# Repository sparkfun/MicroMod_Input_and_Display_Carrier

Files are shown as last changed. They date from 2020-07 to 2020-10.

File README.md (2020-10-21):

# SparkFun MicroMod Input and Display Carrier Board
========================================

SparkFun MicroMod Input and Display Carrier Board

[*SparkFun MicroMod Input and Display Carrier Board (16985)*](https://www.sparkfun.com/products/16985)

The SparkFun MicroMod Input and Display Carrier Board is a great way to add data and input visibility to your MicroMod project. Want to create your own embedded game? How about displaying data that is remotely collected and transmitted by your SparkFun MicroMod Weather Carrier Board and its processor? This is a great option. 

This carrier board combines a 2.4" TFT display, 6 addressable LEDs, onboard voltage regulator, a 6 pin IO connector, and microSD slot with the M.2 pin connector slot so that it can be used with compatible processor boards in our MicroMod ecosystem. 

Repository Contents
-------------------
* **/Firmware** - Example code specific to the Input and Display Carrier Board.
* **/Hardware** - Eagle design files (.brd, .sch)
* **/Production** - Production panel files (.brd)

Documentation
--------------
* **[Hookup Guide](https://learn.sparkfun.com/tutorials/sparkfun-micromod-input-and-display-carrier-board-hookup-guide)** - Basic hookup guide for the SparkFun MicroMod Input and Display Carrier Board.
* **[SparkFun Graphical Datasheets](https://github.com/sparkfun/Graphical_Datasheets)** -Graphical Datasheets for various SparkFun products.
* **[SparkFun HyperDisplay](https://github.com/sparkfun/SparkFun_HyperDisplay/archive/master.zip)** - Base level HyperDisplay library.
* **[SparkFun HyperDisplay ILI9341 Arduino Library](https://github.com/sparkfun/HyperDisplay_ILI9341_ArduinoLibrary/archive/master.zip)** - Mid level HyperDisplay library.
* **[SparkFun_HyperDisplay 4DLCD-320240 Arduino Library](https://github.com/sparkfun/HyperDisplay_4DLCD-320240_ArduinoLibrary/archive/master.zip)** -  Top level HyperDisplay library for the SparkFun MicroMod Input and Display Carrier Board. This library contains the examples for using the Input and Display Carrier Board.
* **[SparkFun MicroMod Button Arduino Library](https://github.com/sparkfun/SparkFun_MicroMod_Button_Arduino_Library)** - Example library to allow the user to determine if buttons on the board are pressed.  
* **[Getting Started with MicroMod](https://learn.sparkfun.com/tutorials/getting-started-with-micromod)** - A tutorial to help you get started with the MicroMod Ecosystem. 
* **[Designing with MicroMod](https://learn.sparkfun.com/tutorials/designing-with-micromod)** - A tutorial to walk you through the specs of the MicroMod processor and carrier board as well as the basics of incorporating the MicroMod form factor into your own PCB designs.

License Information
-------------------

This product is _**open source**_! 

Please review the LICENSE.md file for license information. 

If you have any questions or concerns on licensing, please contact technical support on our [SparkFun forums](https://forum.sparkfun.com/viewforum.php?f=152).

Distributed as-is; no warranty is given.

- Your friends at SparkFun.

_<COLLABORATION CREDIT>_

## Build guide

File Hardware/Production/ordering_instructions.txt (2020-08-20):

panel size, 129x178mm
PCB thickness, 1.6mm
number of layers, 2
soldermask color, Red
silkscreen color, White
oz copper, 1oz
finish, HASL lead free
stencils, top+bottom
pcs per panel, 4
min trace width, 0.1778mm / 0.0070in
min drill size, 0.3810mm / 0.0150in

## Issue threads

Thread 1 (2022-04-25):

Debouncing logic can cause button release to be missed

cbiffle, 2022-04-25:
Because the debouncing logic delays _all_ pin change interrupts, and not further interrupts from the pin that is being debounced, pressing any two buttons and then releasing them at roughly the same time can cause one to stay "pressed," from the perspective of the pressed/clicked registers.

The problem is here: https://github.com/sparkfun/MicroMod_Input_and_Display_Carrier/blob/master/Firmware/Input_and_Display_Button_Master/interrupts.ino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

...where the ISR is simply aborted if the debounce timer hasn't elapsed yet.

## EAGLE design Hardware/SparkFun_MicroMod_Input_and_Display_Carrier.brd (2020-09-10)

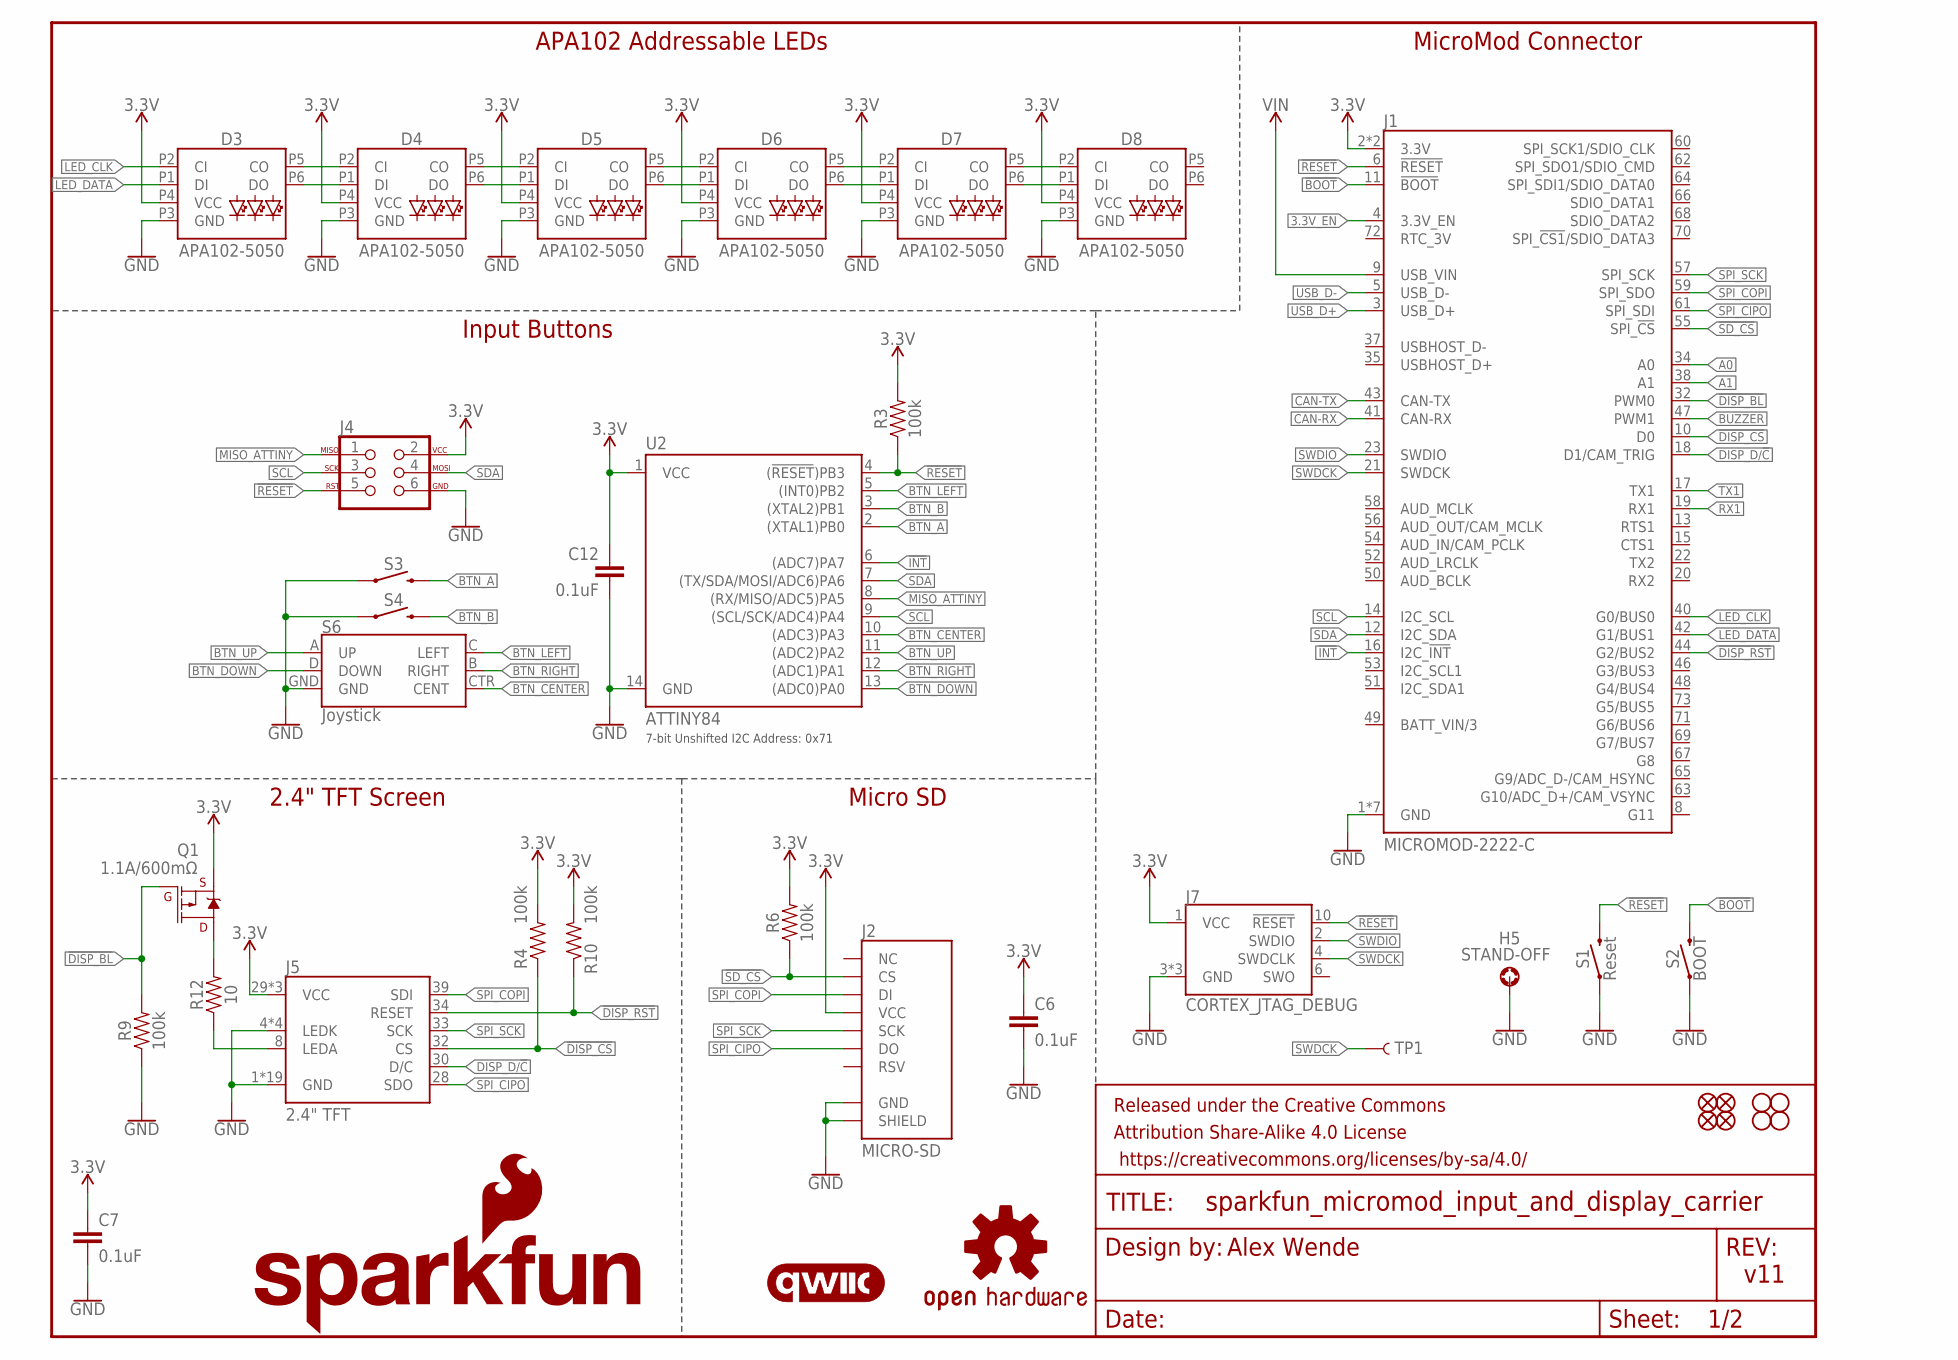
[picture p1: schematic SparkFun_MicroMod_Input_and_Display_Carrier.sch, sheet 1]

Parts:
C6, C7, C12: 0.1uF; 0603
D3, D4, D5, D6, D7, D8: APA102-5050
FD1, FD2, FD3, FD4: FIDUCIALUFIDUCIAL; FIDUCIAL-MICRO
FRAME1: FRAME-LETTER; CREATIVE_COMMONS
H1, H2, H3, H4: STAND-OFF
H5: STAND-OFF; STAND-OFF-REFLOW-M2.5
J1: MICROMOD-2222-C; M.2-CONNECTOR-E
J2: MICRO-SD; MICRO-SD-SOCKET
J4: AVR_SPI_PROG_3X2TESTPOINTS; 2X3_TEST_POINTS
J5: 2.4" TFT; FPC05040-17204
J7: CORTEX_JTAG_DEBUG; 2X5-PTH-1.27MM-NO_SILK
LOGO1: SFE_LOGO_NAME_FLAME.2_INCH; SFE_LOGO_NAME_FLAME_.2
LOGO2: QWIIC_LOGO_5MM; QWIIC_5MM
LOGO3: OSHW-LOGOS; OSHW-LOGO-S
Q1: 1.1A/600mΩ; SOT23-3
R3, R4, R6, R9, R10: 100k; 0603
R12: 10; 1206
S1: Reset; TACTILE_SWITCH_SMD_5.2MM
S2: BOOT; TACTILE_SWITCH_SMD_5.2MM
S3, S4: MOMENTARY-SWITCH-SPST-SMD-5.2MM-TALL; TACTILE_SWITCH_SMD_5.2MM
S6: Joystick; JOYSTICK_MINI
TP1: TEST-POINT3; PAD.03X.03
U2: ATTINY84; SO14

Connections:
3.3V: C6.1, C7.1, C12.1, D3.P4 (VCC), D4.P4 (VCC), D5.P4 (VCC), D6.P4 (VCC), D7.P4 (VCC), D8.P4 (VCC), J1.2 (3.3V), J1.74 (3.3V), J2.VCC, J4.2, J5.29 (VCC), J5.31 (VCC), J5.38 (VCC), J7.1 (VCC), Q1.2 (S), R3.2, R4.2, R6.2, R10.2, U2.1 (VCC); also elsewhere on the board
3.3V_EN: J1.4 (3.3V_EN); also elsewhere on the board
!BOOT: J1.11 (!BOOT!), S2.3 (2), S2.4 (2)
!DISP_BL: J1.32 (PWM0), Q1.1 (G), R9.2
!DISP_CS: J1.10 (D0), J5.32 (CS), R4.1
!DISP_RST: J1.44 (G2/BUS2), J5.34 (RESET), R10.1
!INT: J1.16 (I2C_!INT!), U2.6 ((ADC7)PA7)
!RESET: J1.6 (!RESET!), J4.5, J7.10 (!RESET), R3.1, S1.3 (2), S1.4 (2), U2.4 ((!RESET!)PB3)
!SD_CS: J1.55 (SPI_!CS!), J2.CS, R6.1
A0: J1.34 (A0); also elsewhere on the board
A1: J1.38 (A1); also elsewhere on the board
BTN_A: S3.3 (2), U2.2 ((XTAL1)PB0)
BTN_B: S4.3 (2), U2.3 ((XTAL2)PB1)
BTN_CENTER: S6.CTR (CENT), U2.10 ((ADC3)PA3)
BTN_DOWN: S6.D (DOWN), U2.13 ((ADC0)PA0)
BTN_LEFT: S6.C (LEFT), U2.5 ((INT0)PB2)
BTN_RIGHT: S6.B (RIGHT), U2.12 ((ADC1)PA1)
BTN_UP: S6.A (UP), U2.11 ((ADC2)PA2)
BUZZER: J1.47 (PWM1); also elsewhere on the board
CAN-RX: J1.41 (CAN-RX); also elsewhere on the board
CAN-TX: J1.43 (CAN-TX); also elsewhere on the board
DISP_D/!C: J1.18 (D1/CAM_TRIG), J5.30 (D/C)
GND: C6.2, C7.2, C12.2, D3.P3 (GND), D4.P3 (GND), D5.P3 (GND), D6.P3 (GND), D7.P3 (GND), D8.P3 (GND), H5.1, J1.1 (GND), J1.7 (GND), J1.33 (GND), J1.36 (GND), J1.39 (GND), J1.45 (GND), J1.75 (GND), J2.CD1 (SHIELD), J2.GND, J4.6, J5.1 (GND), J5.4 (LEDK), J5.5 (LEDK), J5.6 (LEDK), J5.7 (LEDK), J5.11 (GND), J5.12 (GND), J5.13 (GND), J5.14 (GND), J5.15 (GND), J5.16 (GND), J5.17 (GND), J5.18 (GND), J5.19 (GND), J5.20 (GND), J5.21 (GND), J5.22 (GND), J5.23 (GND), J5.24 (GND), J5.25 (GND), J5.26 (GND), J5.27 (GND), J5.40 (GND), J7.3 (GND), J7.5 (GND), J7.9 (GND), R9.1, S1.1, S1.2 (1), S2.1, S2.2 (1), S3.1, S4.1, S6.GND, U2.14 (GND); also elsewhere on the board
LED_CLK: D3.P2 (CI), J1.40 (G0/BUS0)
LED_DATA: D3.P1 (DI), J1.42 (G1/BUS1)
MISO_ATTINY: J4.1, U2.8 ((RX/MISO/ADC5)PA5)
unnamed: J5.8 (LEDA), R12.1
unnamed: Q1.3 (D), R12.2
unnamed: D3.P5 (CO), D4.P2 (CI)
unnamed: D3.P6 (DO), D4.P1 (DI)
unnamed: D4.P5 (CO), D5.P2 (CI)
unnamed: D4.P6 (DO), D5.P1 (DI)
unnamed: D5.P5 (CO), D6.P2 (CI)
unnamed: D5.P6 (DO), D6.P1 (DI)
unnamed: D6.P5 (CO), D7.P2 (CI)
unnamed: D6.P6 (DO), D7.P1 (DI)
unnamed: D7.P5 (CO), D8.P2 (CI)
unnamed: D7.P6 (DO), D8.P1 (DI)
RX1: J1.19 (RX1); also elsewhere on the board
SCL: J1.14 (I2C_SCL), J4.3, U2.9 ((SCL/SCK/ADC4)PA4); also elsewhere on the board
SDA: J1.12 (I2C_SDA), J4.4, U2.7 ((TX/SDA/MOSI/ADC6)PA6); also elsewhere on the board
SPI_CIPO: J1.61 (SPI_SDI), J2.DO, J5.28 (SDO)
SPI_COPI: J1.59 (SPI_SDO), J2.DI, J5.39 (SDI)
SPI_SCK: J1.57 (SPI_SCK), J2.SCLK (SCK), J5.33 (SCK)
SWDCK: J1.21 (SWDCK), J7.4 (SWDCLK), TP1.P$1
SWDIO: J1.23 (SWDIO), J7.2 (SWDIO)
TX1: J1.17 (TX1); also elsewhere on the board
USB_D+: J1.3 (USB_D+); also elsewhere on the board
USB_D-: J1.5 (USB_D-); also elsewhere on the board
VIN: J1.9 (USB_VIN); also elsewhere on the board

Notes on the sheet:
7-bit Unshifted I2C Address: 0x71
Alex Wende
v11
Micro SD
2.4" TFT Screen
Input Buttons
APA102 Addressable LEDs
MicroMod Connector

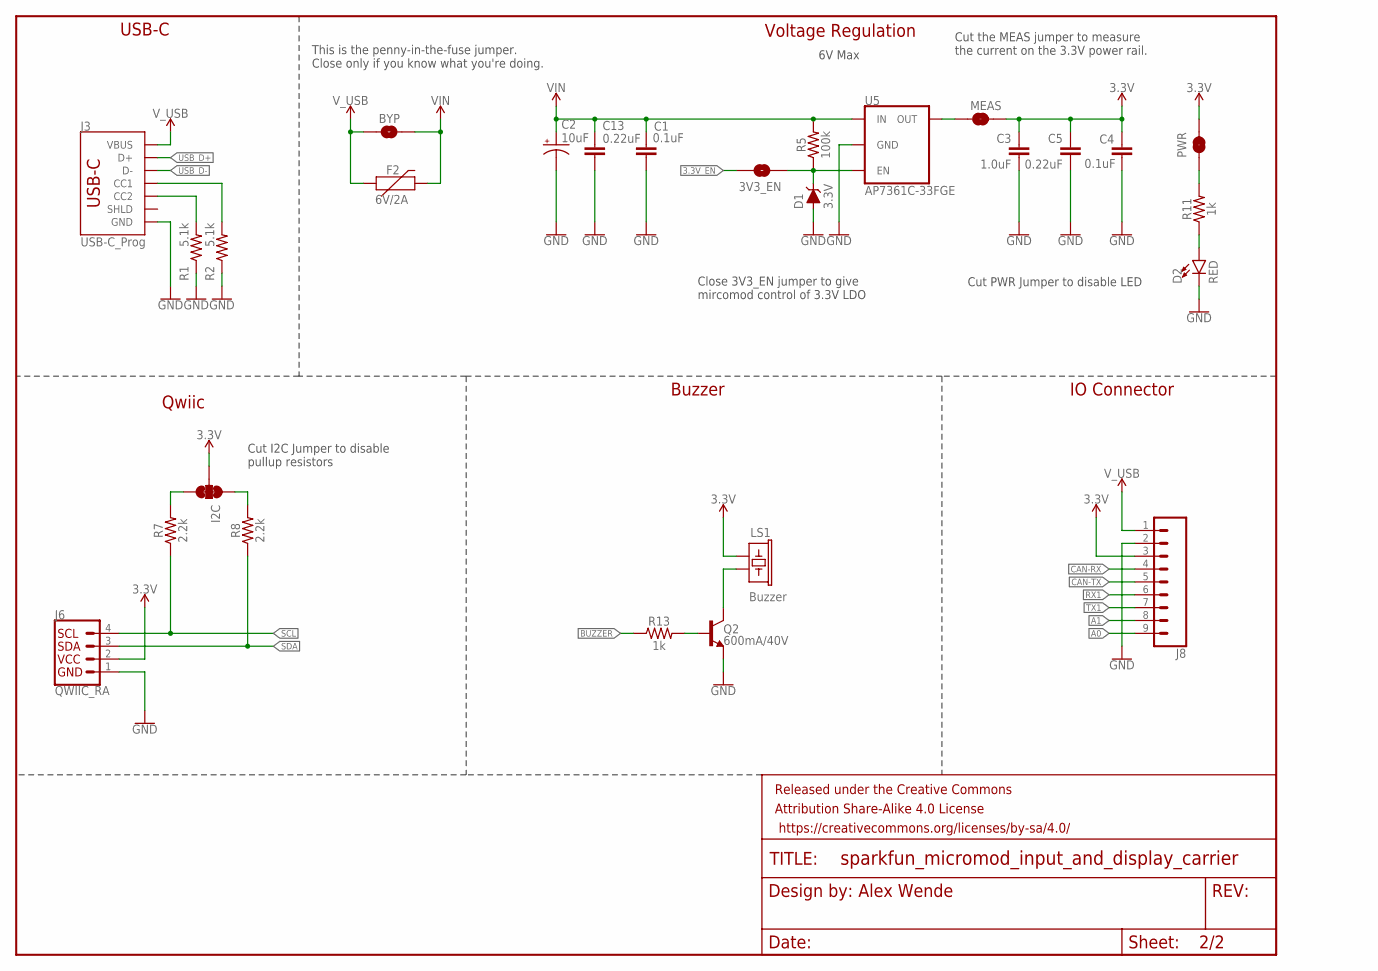
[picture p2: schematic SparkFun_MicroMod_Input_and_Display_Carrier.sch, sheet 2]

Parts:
3V3_EN: JUMPER-SMT_2_NO_SILK; SMT-JUMPER_2_NO_SILK
BYP: JUMPER-SMT_2_NO_SILK; SMT-JUMPER_2_NO_SILK
C1, C4: 0.1uF; 0603
C2: 10uF; EIA3216
C3: 1.0uF; 0603
C5, C13: 0.22uF; 0603
D1: 3.3V; SOD-323
D2: RED; LED-0603
F2: 6V/2A; 1210
FRAME2: FRAME-LETTERNO_PACKAGE; DUMMY
I2C: JUMPER-SMT_3_2-NC_TRACE_SILK; SMT-JUMPER_3_2-NC_TRACE_SILK
J3: USB-C_Prog; USB-C-16P-2LAYER-PADS
J6: QWIIC_RA; JST04_1MM_RA
J8: CONN_09NO_SILK; 1X09_NO_SILK
LS1: Buzzer; BUZZER-CCV
MEAS: JUMPER-COMBO_2_NC_TRACE; COMBO-JUMPER_2_NC_TRACE
PWR: JUMPER-SMT_2_NC_TRACE_SILK; SMT-JUMPER_2_NC_TRACE_SILK
Q2: 600mA/40V; SOT23-3
R1, R2: 5.1k; 0603
R5: 100k; 0603
R7, R8: 2.2k; 0603
R11, R13: 1k; 0603
U5: AP7361C-33FGE; UDFN-8

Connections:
3.3V: C3.1, C4.1, C5.1, I2C.2, J6.2, J8.3, LS1.+ (1), MEAS.2, MEAS.4 (2), PWR.2; also elsewhere on the board
3.3V_EN: 3V3_EN.1; also elsewhere on the board
A0: J8.9; also elsewhere on the board
A1: J8.8; also elsewhere on the board
BUZZER: R13.1; also elsewhere on the board
CAN-RX: J8.4; also elsewhere on the board
CAN-TX: J8.5; also elsewhere on the board
ENABLE: 3V3_EN.2, D1.C, R5.1, U5.5 (EN)
GND: C1.2, C2.-, C3.2, C4.2, C5.2, C13.2, D1.A, D2.C, J3.GND, J3.GND2 (GND), J6.1, J8.2, Q2.2 (E), R1.1, R2.1, U5.4 (GND), U5.EP (GND); also elsewhere on the board
unnamed: I2C.3, R7.2
unnamed: I2C.1, R8.2
unnamed: LS1.- (2), Q2.3 (C)
unnamed: Q2.1 (B), R13.2
unnamed: J3.A5 (CC1), R2.2
unnamed: J3.B5 (CC2), R1.2
unnamed: PWR.1, R11.2
unnamed: D2.A, R11.1
unnamed: MEAS.1, MEAS.3 (1), U5.1 (OUT)
RX1: J8.6; also elsewhere on the board
SCL: J6.4, R7.1; also elsewhere on the board
SDA: J6.3, R8.1; also elsewhere on the board
TX1: J8.7; also elsewhere on the board
USB_D+: J3.A6 (D+), J3.B6 (D+); also elsewhere on the board
USB_D-: J3.A7 (D-), J3.B7 (D-); also elsewhere on the board
VIN: BYP.2, C1.1, C2.+, C13.1, F2.2, R5.2, U5.8 (IN); also elsewhere on the board
V_USB: BYP.1, F2.1, J3.VBUS1 (VBUS), J3.VBUS2 (VBUS), J8.1

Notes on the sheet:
This is the penny-in-the-fuse jumper. Close only if you know what you're doing.
Voltage Regulation
USB-C
Alex Wende
Qwiic
Cut PWR Jumper to disable LED
Cut I2C Jumper to disable pullup resistors
Close 3V3_EN jumper to give mircomod control of 3.3V LDO
Buzzer
IO Connector
6V Max
Cut the MEAS jumper to measure the current on the 3.3V power rail.

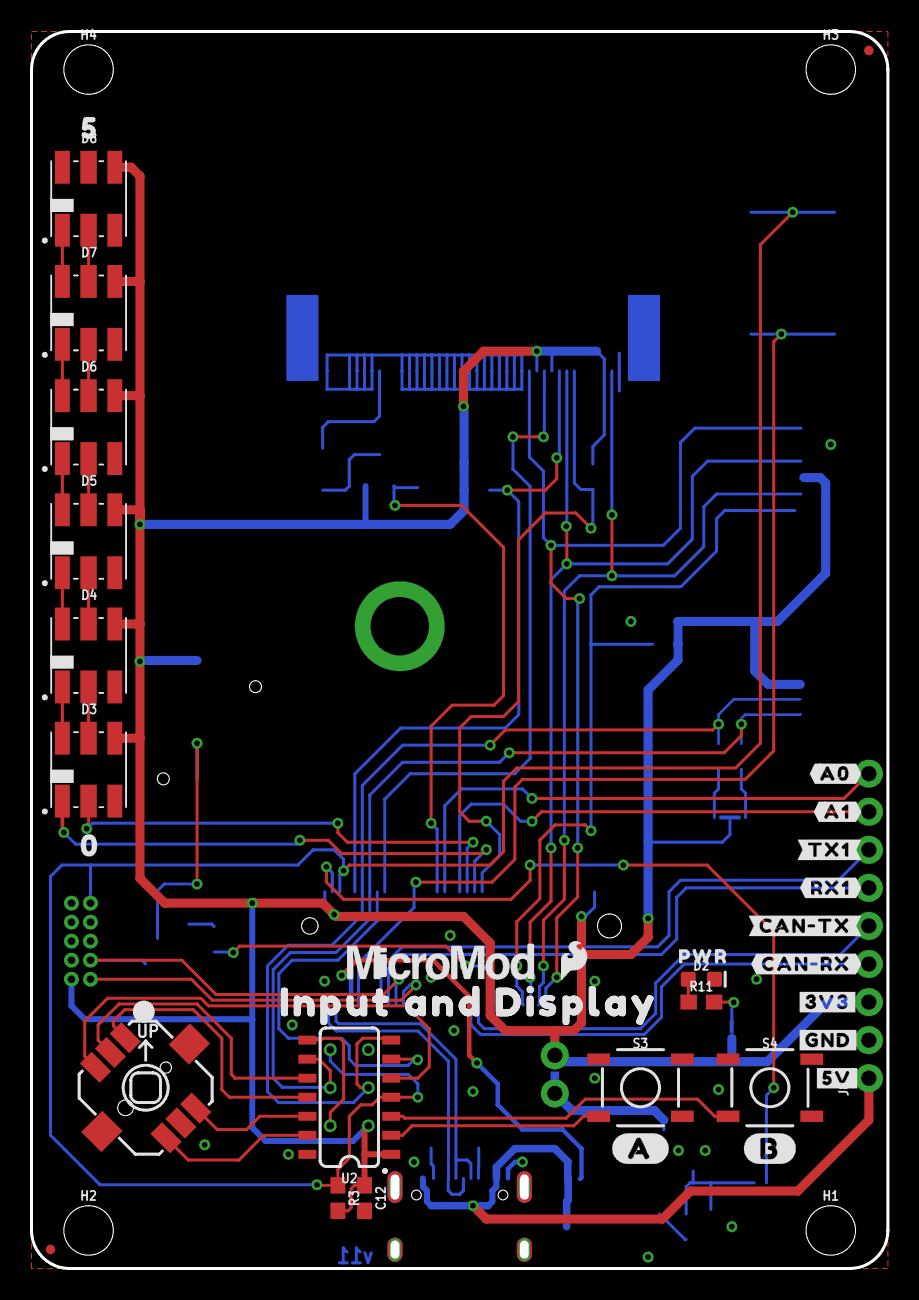
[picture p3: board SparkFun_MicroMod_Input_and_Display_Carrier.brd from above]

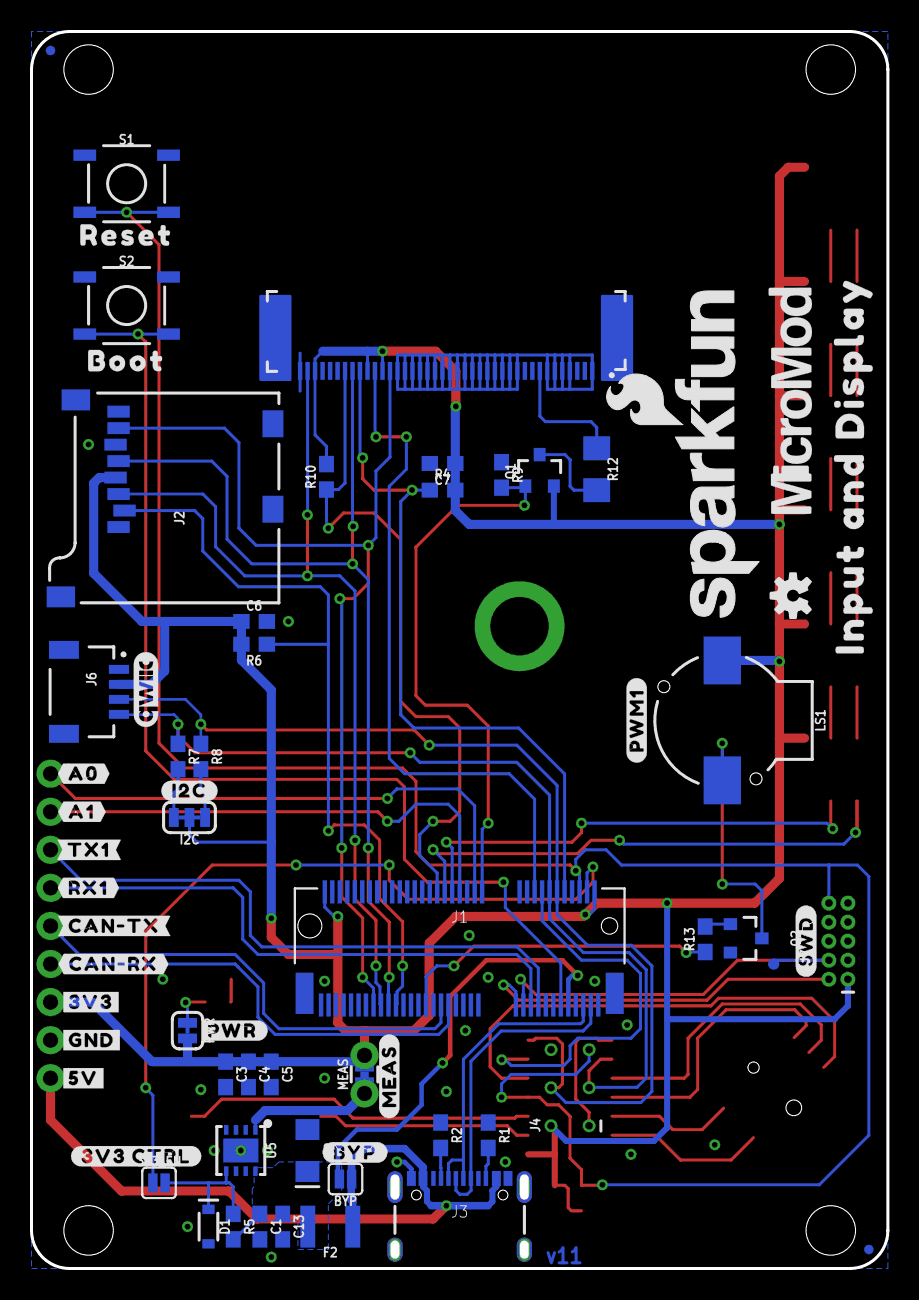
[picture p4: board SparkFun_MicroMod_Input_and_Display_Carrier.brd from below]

Board: 2 copper layers, 57.1 x 82.5 mm, 107 parts (66 on the bottom side), 61 nets.

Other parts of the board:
U$1: MICROMOD_LOGO_.5
U$2, U$16, U$17: INPUT_AND_DISPLAY0
U$3: SFE_LOGO_FLAME_.1
U$4: BOOT0
U$5: #A#0
U$6: #B#0
U$7: 00
U$8: 50
U$9: RESET0
U$10: MICROMOD_LOGO_.6
U$11: #MEAS#0
U$12: #I2C#0
U$13: PWR0
U$14: #BYP#0
U$15: #SWD#0
U$18, U$38: #5V#0
U$19: #PWR#0
U$20: #3V3_CTRL#0
U$21: #PWM1#0
U$22, U$23: #A0#0
U$24, U$25: #A1#0
U$26, U$27: #TX1#0
U$28, U$31: #3V3#0
U$29, U$30: #GND#0
U$32, U$33: #RX1#0
U$34, U$35: #CAN#RX#0
U$36, U$37: #CAN#TX#0

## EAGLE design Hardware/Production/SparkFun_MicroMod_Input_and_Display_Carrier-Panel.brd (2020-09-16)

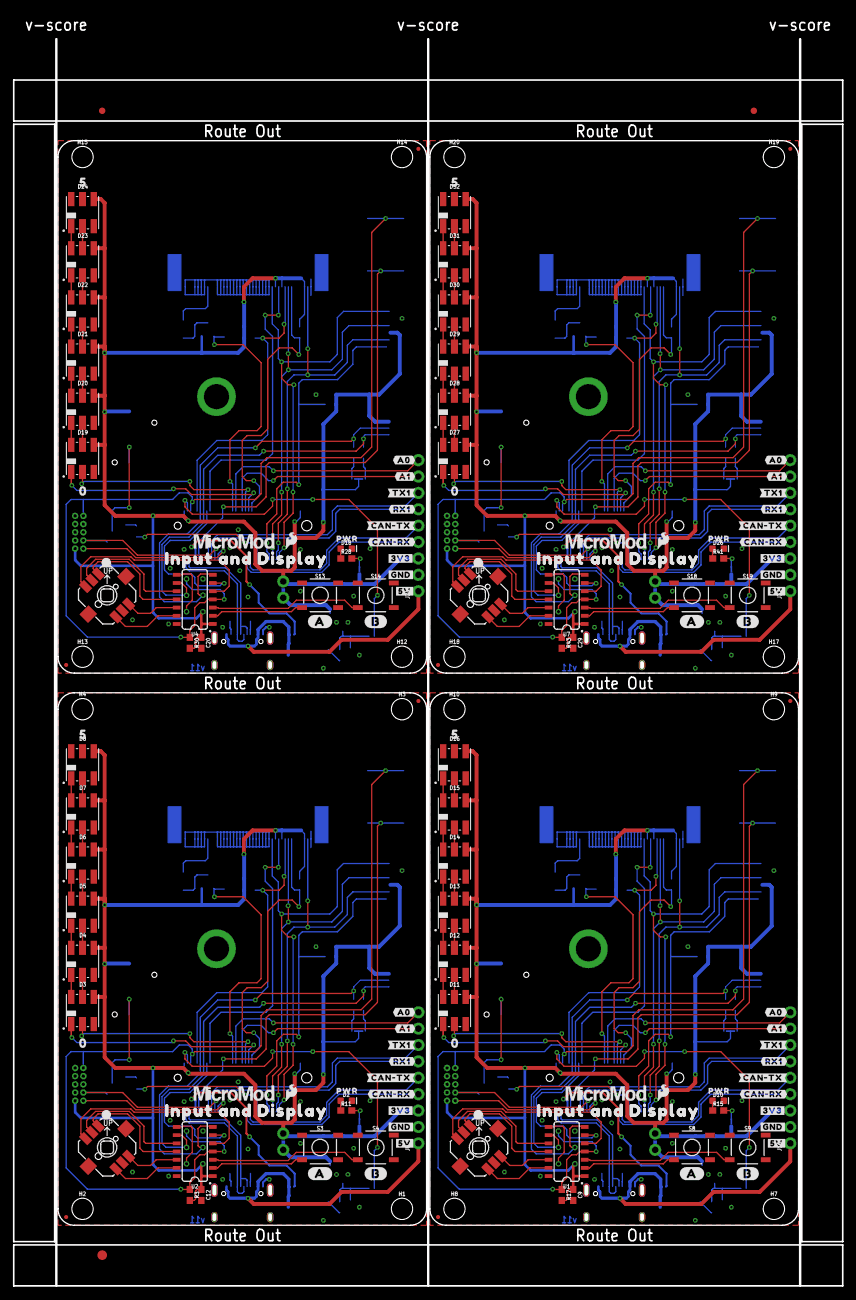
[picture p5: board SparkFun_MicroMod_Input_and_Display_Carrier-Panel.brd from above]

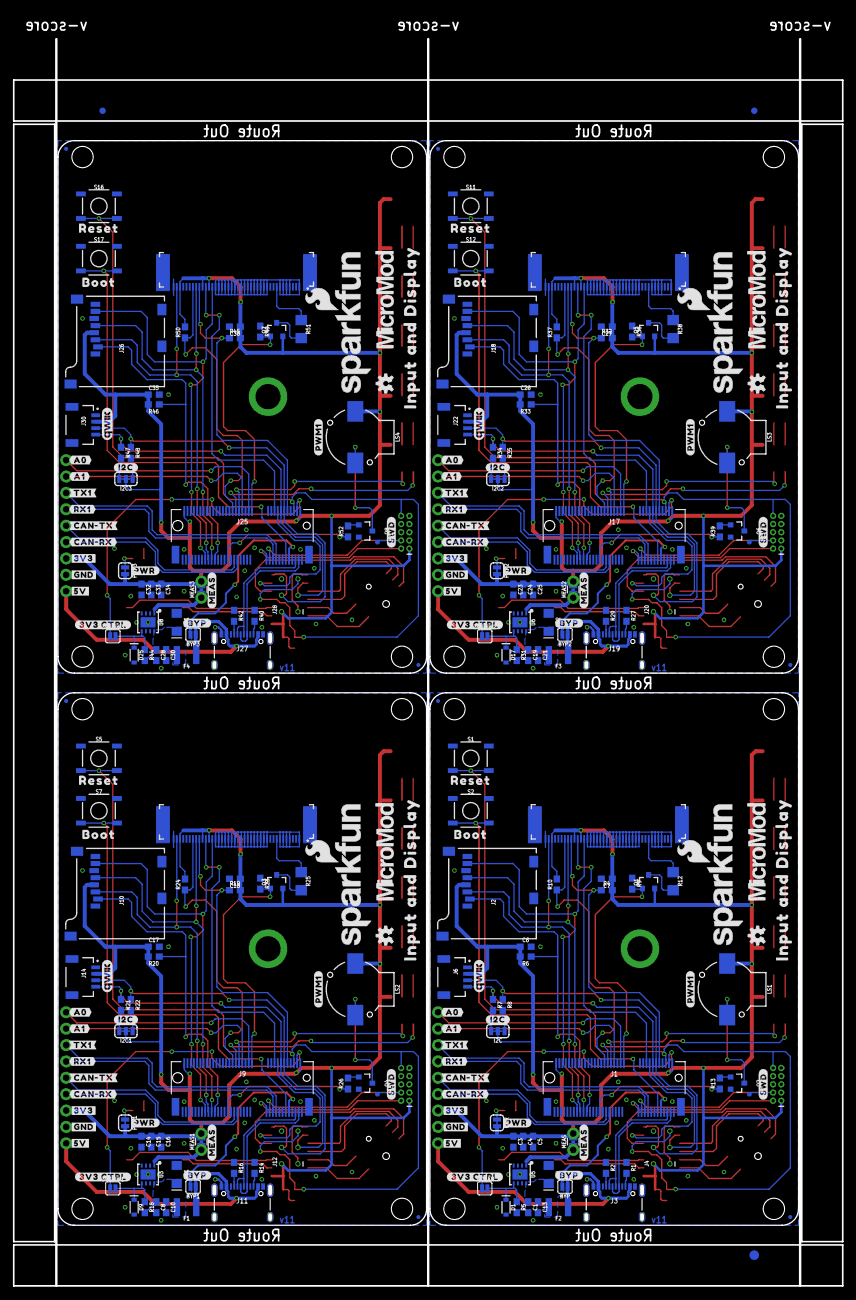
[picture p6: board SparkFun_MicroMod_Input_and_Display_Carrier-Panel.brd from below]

Board: 2 copper layers, 128.5 x 193.3 mm, 434 parts (267 on the bottom side), 244 nets.

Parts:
3V3_EN, 3V3_EN1, 3V3_EN2, 3V3_EN3: SMT-JUMPER_2_NO_SILK
BYP, BYP1, BYP2, BYP3: JUMPER-SMT_2_NO_SILK; SMT-JUMPER_2_NO_SILK
C1, C4, C6, C7, C8, C9, C12, C15, C17, C18, C19, C20, C24, C26, C27, C28, C29, C33, C35, C36: 0.1uF; 0603
C2, C11, C22, C31: 10uF; EIA3216
C3, C14, C23, C32: 1.0uF; 0603
C5, C10, C13, C16, C21, C25, C30, C34: 0.22uF; 0603
D1, D9, D17, D25: 3.3V; SOD-323
D2, D10, D18, D26: RED; LED-0603
D3, D4, D5, D6, D7, D8, D11, D12, D13, D14, D15, D16, D19, D20, D21, D22, D23, D24, D27, D28, D29, D30, D31, D32: APA102-5050
E$1, E$2, E$3, E$4: FIDUCIAL-1X2
E$5, E$6: FIDUCIAL-1.5X3
F1, F2, F3, F4: 6V/2A; 1210
FD1, FD2, FD3, FD4, FD5, FD6, FD7, FD8, FD9, FD10, FD11, FD12, FD13, FD14, FD15, FD16: FIDUCIALUFIDUCIAL; FIDUCIAL-MICRO
FRAME1, FRAME3, FRAME5, FRAME7: FRAME-LETTER; CREATIVE_COMMONS
FRAME2, FRAME4, FRAME6, FRAME8: FRAME-LETTERNO_PACKAGE; DUMMY
H1, H2, H3, H4, H7, H8, H9, H10, H12, H13, H14, H15, H17, H18, H19, H20: STAND-OFF
H5, H6, H11, H16: STAND-OFF; STAND-OFF-REFLOW-M2.5
I2C, I2C1, I2C2, I2C3: SMT-JUMPER_3_2-NC_TRACE_SILK
J1, J9, J17, J25: MICROMOD-2222-C; M.2-CONNECTOR-E
J2, J10, J18, J26: MICRO-SD; MICRO-SD-SOCKET
J3, J11, J19, J27: USB-C_Prog; USB-C-16P-2LAYER-PADS
J4, J12, J20, J28: AVR_SPI_PROG_3X2TESTPOINTS; 2X3_TEST_POINTS
J5, J13, J21, J29: 2.4" TFT; FPC05040-17204
J6, J14, J22, J30: QWIIC_RA; JST04_1MM_RA
J7, J15, J23, J31: CORTEX_JTAG_DEBUG; 2X5-PTH-1.27MM-NO_SILK
J8, J16, J24, J32: 1X09_NO_SILK
LOGO1, LOGO4, LOGO7, LOGO10: SFE_LOGO_NAME_FLAME.2_INCH; SFE_LOGO_NAME_FLAME_.2
LOGO2, LOGO5, LOGO8, LOGO11: QWIIC_LOGO_5MM; QWIIC_5MM
LOGO3, LOGO6, LOGO9, LOGO12: OSHW-LOGOS; OSHW-LOGO-S
LS1, LS2, LS3, LS4: Buzzer; BUZZER-CCV
MEAS, MEAS1, MEAS2, MEAS3: COMBO-JUMPER_2_NC_TRACE
PWR, PWR1, PWR2, PWR3: SMT-JUMPER_2_NC_TRACE_SILK
Q1, Q3, Q5, Q7: 1.1A/600mΩ; SOT23-3
Q2, Q4, Q6, Q8: 600mA/40V; SOT23-3
R1, R2, R14, R16, R27, R29, R40, R42: 5.1k; 0603
R3, R4, R5, R6, R9, R10, R17, R18, R19, R20, R23, R24, R30, R31, R32, R33, R36, R37, R43, R44, R45, R46, R49, R50: 100k; 0603
R7, R8, R21, R22, R34, R35, R47, R48: 2.2k; 0603
R11, R13, R15, R26, R28, R39, R41, R52: 1k; 0603
R12, R25, R38, R51: 10; 1206
S1, S5, S11, S16: Reset; TACTILE_SWITCH_SMD_5.2MM
S2, S7, S12, S17: BOOT; TACTILE_SWITCH_SMD_5.2MM
S3, S4, S8, S9, S13, S14, S18, S19: MOMENTARY-SWITCH-SPST-SMD-5.2MM-TALL; TACTILE_SWITCH_SMD_5.2MM
S6, S10, S15, S20: Joystick; JOYSTICK_MINI
TP1, TP2, TP3, TP4: PAD.03X.03
U1, U2, U4, U7: ATTINY84; SO14
U3, U5, U6, U8: AP7361C-33FGE; UDFN-8
U$1, U$39, U$77, U$115: MICROMOD_LOGO_.5
U$2, U$16, U$17, U$40, U$54, U$55, U$78, U$92, U$93, U$116, U$130, U$131: INPUT_AND_DISPLAY0
U$3, U$45, U$83, U$121: SFE_LOGO_FLAME_.1
U$4, U$46, U$84, U$122: BOOT0
U$5, U$41, U$79, U$117: #A#0
U$6, U$42, U$80, U$118: #B#0
U$7, U$43, U$81, U$119: 00
U$8, U$44, U$82, U$120: 50
U$9, U$47, U$85, U$123: RESET0
U$10, U$51, U$89, U$127: MICROMOD_LOGO_.6
U$11, U$48, U$86, U$124: #MEAS#0
U$12, U$49, U$87, U$125: #I2C#0
U$13, U$50, U$88, U$126: PWR0
U$14, U$52, U$90, U$128: #BYP#0
U$15, U$53, U$91, U$129: #SWD#0
U$18, U$38, U$75, U$76, U$113, U$114, U$151, U$152: #5V#0
U$19, U$56, U$94, U$132: #PWR#0
U$20, U$57, U$95, U$133: #3V3_CTRL#0
U$21, U$58, U$96, U$134: #PWM1#0
U$22, U$23, U$63, U$64, U$101, U$102, U$139, U$140: #A0#0
U$24, U$25, U$65, U$66, U$103, U$104, U$141, U$142: #A1#0
U$26, U$27, U$67, U$68, U$105, U$106, U$143, U$144: #TX1#0
U$28, U$31, U$59, U$62, U$97, U$100, U$135, U$138: #3V3#0
U$29, U$30, U$60, U$61, U$98, U$99, U$136, U$137: #GND#0
U$32, U$33, U$69, U$70, U$107, U$108, U$145, U$146: #RX1#0
U$34, U$35, U$71, U$72, U$109, U$110, U$147, U$148: #CAN#RX#0
U$36, U$37, U$73, U$74, U$111, U$112, U$149, U$150: #CAN#TX#0

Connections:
3.3V: C3.1, C4.1, C5.1, C6.1, C7.1, C12.1, D3.P4, D4.P4, D5.P4, D6.P4, D7.P4, D8.P4, I2C.2, J1.2, J1.74, J2.VCC, J4.2, J5.29, J5.31, J5.38, J6.2, J7.1, J8.3, LS1.+, MEAS.2, MEAS.4, PWR.2, Q1.2, R3.2, R4.2, R6.2, R10.2, U2.1
3.3V1: C9.1, C14.1, C15.1, C16.1, C17.1, C18.1, D11.P4, D12.P4, D13.P4, D14.P4, D15.P4, D16.P4, I2C1.2, J9.2, J9.74, J10.VCC, J12.2, J13.29, J13.31, J13.38, J14.2, J15.1, J16.3, LS2.+, MEAS1.2, MEAS1.4, PWR1.2, Q3.2, R17.2, R19.2, R20.2, R24.2, U1.1
3.3V2: C20.1, C23.1, C24.1, C25.1, C26.1, C27.1, D19.P4, D20.P4, D21.P4, D22.P4, D23.P4, D24.P4, I2C2.2, J17.2, J17.74, J18.VCC, J20.2, J21.29, J21.31, J21.38, J22.2, J23.1, J24.3, LS3.+, MEAS2.2, MEAS2.4, PWR2.2, Q5.2, R30.2, R32.2, R33.2, R37.2, U4.1
3.3V3: C29.1, C32.1, C33.1, C34.1, C35.1, C36.1, D27.P4, D28.P4, D29.P4, D30.P4, D31.P4, D32.P4, I2C3.2, J25.2, J25.74, J26.VCC, J28.2, J29.29, J29.31, J29.38, J30.2, J31.1, J32.3, LS4.+, MEAS3.2, MEAS3.4, PWR3.2, Q7.2, R43.2, R45.2, R46.2, R50.2, U7.1
3.3V_EN: 3V3_EN.1, J1.4
3.3V_EN1: 3V3_EN1.1, J9.4
3.3V_EN2: 3V3_EN2.1, J17.4
3.3V_EN3: 3V3_EN3.1, J25.4
!BOOT: J1.11, S2.3, S2.4
!BOOT1: J9.11, S7.3, S7.4
!BOOT2: J17.11, S12.3, S12.4
!BOOT3: J25.11, S17.3, S17.4
!DISP_BL: J1.32, Q1.1, R9.2
!DISP_BL1: J9.32, Q3.1, R23.2
!DISP_BL2: J17.32, Q5.1, R36.2
!DISP_BL3: J25.32, Q7.1, R49.2
!DISP_CS: J1.10, J5.32, R4.1
!DISP_CS1: J9.10, J13.32, R19.1
!DISP_CS2: J17.10, J21.32, R32.1
!DISP_CS3: J25.10, J29.32, R45.1
!DISP_RST: J1.44, J5.34, R10.1
!DISP_RST1: J9.44, J13.34, R24.1
!DISP_RST2: J17.44, J21.34, R37.1
!DISP_RST3: J25.44, J29.34, R50.1
!INT: J1.16, U2.6
!INT1: J9.16, U1.6
!INT2: J17.16, U4.6
!INT3: J25.16, U7.6
!RESET: J1.6, J4.5, J7.10, R3.1, S1.3, S1.4, U2.4
!RESET1: J9.6, J12.5, J15.10, R17.1, S5.3, S5.4, U1.4
!RESET2: J17.6, J20.5, J23.10, R30.1, S11.3, S11.4, U4.4
!RESET3: J25.6, J28.5, J31.10, R43.1, S16.3, S16.4, U7.4
!SD_CS: J1.55, J2.CS, R6.1
!SD_CS1: J9.55, J10.CS, R20.1
!SD_CS2: J17.55, J18.CS, R33.1
!SD_CS3: J25.55, J26.CS, R46.1
A0: J1.34, J8.9
A1: J1.38, J8.8
A2: J9.34, J16.9
A3: J9.38, J16.8
A4: J17.34, J24.9
A5: J17.38, J24.8
A6: J25.34, J32.9
A7: J25.38, J32.8
BTN_A: S3.3, U2.2
BTN_A1: S8.3, U1.2
BTN_A2: S13.3, U4.2
BTN_A3: S18.3, U7.2
BTN_B: S4.3, U2.3
BTN_B1: S9.3, U1.3
BTN_B2: S14.3, U4.3
BTN_B3: S19.3, U7.3
BTN_CENTER: S6.CTR, U2.10
BTN_CENTER1: S10.CTR, U1.10
BTN_CENTER2: S15.CTR, U4.10
BTN_CENTER3: S20.CTR, U7.10
BTN_DOWN: S6.D, U2.13
BTN_DOWN1: S10.D, U1.13
BTN_DOWN2: S15.D, U4.13
BTN_DOWN3: S20.D, U7.13
BTN_LEFT: S6.C, U2.5
BTN_LEFT1: S10.C, U1.5
BTN_LEFT2: S15.C, U4.5
BTN_LEFT3: S20.C, U7.5
BTN_RIGHT: S6.B, U2.12
BTN_RIGHT1: S10.B, U1.12
BTN_RIGHT2: S15.B, U4.12
BTN_RIGHT3: S20.B, U7.12
BTN_UP: S6.A, U2.11
BTN_UP1: S10.A, U1.11
BTN_UP2: S15.A, U4.11
BTN_UP3: S20.A, U7.11
BUZZER: J1.47, R13.1
BUZZER1: J9.47, R26.1
BUZZER2: J17.47, R39.1
BUZZER3: J25.47, R52.1
CAN-RX: J1.41, J8.4
CAN-RX1: J9.41, J16.4
CAN-RX2: J17.41, J24.4
CAN-RX3: J25.41, J32.4
CAN-TX: J1.43, J8.5
CAN-TX1: J9.43, J16.5
CAN-TX2: J17.43, J24.5
CAN-TX3: J25.43, J32.5
DISP_D/!C: J1.18, J5.30
DISP_D/!C1: J9.18, J13.30
DISP_D/!C2: J17.18, J21.30
DISP_D/!C3: J25.18, J29.30
ENABLE: 3V3_EN.2, D1.C, R5.1, U5.5
ENABLE1: 3V3_EN1.2, D9.C, R18.1, U3.5
ENABLE2: 3V3_EN2.2, D17.C, R31.1, U6.5
ENABLE3: 3V3_EN3.2, D25.C, R44.1, U8.5
GND: C1.2, C2.-, C3.2, C4.2, C5.2, C6.2, C7.2, C12.2, C13.2, D1.A, D2.C, D3.P3, D4.P3, D5.P3, D6.P3, D7.P3, D8.P3, H5.1, J1.1, J1.7, J1.33, J1.36, J1.39, J1.45, J1.75, J2.CD1, J2.GND, J3.GND, J3.GND2, J4.6, J5.1, J5.4, J5.5, J5.6, J5.7, J5.11, J5.12, J5.13, J5.14, J5.15, J5.16, J5.17, J5.18, J5.19, J5.20, J5.21, J5.22, J5.23, J5.24, J5.25, J5.26, J5.27, J5.40, J6.1, J7.3, J7.5, J7.9, J8.2, Q2.2, R1.1, R2.1, R9.1, S1.1, S1.2, S2.1, S2.2, S3.1, S4.1, S6.GND, U2.14, U5.4, U5.EP
GND1: C8.2, C9.2, C10.2, C11.-, C14.2, C15.2, C16.2, C17.2, C18.2, D9.A, D10.C, D11.P3, D12.P3, D13.P3, D14.P3, D15.P3, D16.P3, H6.1, J9.1, J9.7, J9.33, J9.36, J9.39, J9.45, J9.75, J10.CD1, J10.GND, J11.GND, J11.GND2, J12.6, J13.1, J13.4, J13.5, J13.6, J13.7, J13.11, J13.12, J13.13, J13.14, J13.15, J13.16, J13.17, J13.18, J13.19, J13.20, J13.21, J13.22, J13.23, J13.24, J13.25, J13.26, J13.27, J13.40, J14.1, J15.3, J15.5, J15.9, J16.2, Q4.2, R14.1, R16.1, R23.1, S5.1, S5.2, S7.1, S7.2, S8.1, S9.1, S10.GND, U1.14, U3.4, U3.EP
GND2: C19.2, C20.2, C21.2, C22.-, C23.2, C24.2, C25.2, C26.2, C27.2, D17.A, D18.C, D19.P3, D20.P3, D21.P3, D22.P3, D23.P3, D24.P3, H11.1, J17.1, J17.7, J17.33, J17.36, J17.39, J17.45, J17.75, J18.CD1, J18.GND, J19.GND, J19.GND2, J20.6, J21.1, J21.4, J21.5, J21.6, J21.7, J21.11, J21.12, J21.13, J21.14, J21.15, J21.16, J21.17, J21.18, J21.19, J21.20, J21.21, J21.22, J21.23, J21.24, J21.25, J21.26, J21.27, J21.40, J22.1, J23.3, J23.5, J23.9, J24.2, Q6.2, R27.1, R29.1, R36.1, S11.1, S11.2, S12.1, S12.2, S13.1, S14.1, S15.GND, U4.14, U6.4, U6.EP
GND3: C28.2, C29.2, C30.2, C31.-, C32.2, C33.2, C34.2, C35.2, C36.2, D25.A, D26.C, D27.P3, D28.P3, D29.P3, D30.P3, D31.P3, D32.P3, H16.1, J25.1, J25.7, J25.33, J25.36, J25.39, J25.45, J25.75, J26.CD1, J26.GND, J27.GND, J27.GND2, J28.6, J29.1, J29.4, J29.5, J29.6, J29.7, J29.11, J29.12, J29.13, J29.14, J29.15, J29.16, J29.17, J29.18, J29.19, J29.20, J29.21, J29.22, J29.23, J29.24, J29.25, J29.26, J29.27, J29.40, J30.1, J31.3, J31.5, J31.9, J32.2, Q8.2, R40.1, R42.1, R49.1, S16.1, S16.2, S17.1, S17.2, S18.1, S19.1, S20.GND, U7.14, U8.4, U8.EP
LED_CLK: D3.P2, J1.40
LED_CLK1: D11.P2, J9.40
LED_CLK2: D19.P2, J17.40
LED_CLK3: D27.P2, J25.40
LED_DATA: D3.P1, J1.42
LED_DATA1: D11.P1, J9.42
LED_DATA2: D19.P1, J17.42
LED_DATA3: D27.P1, J25.42
MISO_ATTINY: J4.1, U2.8
MISO_ATTINY1: J12.1, U1.8
MISO_ATTINY2: J20.1, U4.8
MISO_ATTINY3: J28.1, U7.8
unnamed: I2C.3, R7.2
unnamed: I2C.1, R8.2
unnamed: J5.8, R12.1
unnamed: Q1.3, R12.2
unnamed: LS1.-, Q2.3
unnamed: Q2.1, R13.2
unnamed: J11.A5, R16.2
unnamed: J11.B5, R14.2
unnamed: PWR1.1, R15.2
unnamed: D10.A, R15.1
unnamed: D3.P5, D4.P2
unnamed: MEAS1.1, MEAS1.3, U3.1
unnamed: D11.P5, D12.P2
unnamed: D3.P6, D4.P1
unnamed: D11.P6, D12.P1
unnamed: D12.P5, D13.P2
unnamed: D12.P6, D13.P1
unnamed: D13.P5, D14.P2
unnamed: J3.A5, R2.2
unnamed: J3.B5, R1.2
unnamed: PWR.1, R11.2
unnamed: D2.A, R11.1
unnamed: MEAS.1, MEAS.3, U5.1
unnamed: D4.P5, D5.P2
unnamed: D4.P6, D5.P1
unnamed: D5.P5, D6.P2
unnamed: D5.P6, D6.P1
unnamed: D6.P5, D7.P2
unnamed: D6.P6, D7.P1
unnamed: D7.P5, D8.P2
unnamed: D7.P6, D8.P1
unnamed: D13.P6, D14.P1
unnamed: D14.P5, D15.P2
unnamed: D14.P6, D15.P1
unnamed: D15.P5, D16.P2
unnamed: D15.P6, D16.P1
unnamed: I2C1.3, R21.2
unnamed: I2C1.1, R22.2
unnamed: J13.8, R25.1
unnamed: Q3.3, R25.2
unnamed: LS2.-, Q4.3
unnamed: Q4.1, R26.2
unnamed: J19.A5, R29.2
unnamed: J19.B5, R27.2
unnamed: PWR2.1, R28.2
unnamed: D18.A, R28.1
unnamed: MEAS2.1, MEAS2.3, U6.1
unnamed: D19.P5, D20.P2
unnamed: D19.P6, D20.P1
unnamed: D20.P5, D21.P2
unnamed: D20.P6, D21.P1
unnamed: D21.P5, D22.P2
unnamed: D21.P6, D22.P1
unnamed: D22.P5, D23.P2
unnamed: D22.P6, D23.P1
unnamed: D23.P5, D24.P2
unnamed: D23.P6, D24.P1
unnamed: I2C2.3, R34.2
unnamed: I2C2.1, R35.2
unnamed: J21.8, R38.1
unnamed: Q5.3, R38.2
unnamed: LS3.-, Q6.3
unnamed: Q6.1, R39.2
unnamed: J27.A5, R42.2
unnamed: J27.B5, R40.2
unnamed: PWR3.1, R41.2
unnamed: D26.A, R41.1
unnamed: MEAS3.1, MEAS3.3, U8.1
unnamed: D27.P5, D28.P2
unnamed: D27.P6, D28.P1
unnamed: D28.P5, D29.P2
unnamed: D28.P6, D29.P1
unnamed: D29.P5, D30.P2
unnamed: D29.P6, D30.P1
unnamed: D30.P5, D31.P2
unnamed: D30.P6, D31.P1
unnamed: D31.P5, D32.P2
unnamed: D31.P6, D32.P1
unnamed: I2C3.3, R47.2
unnamed: I2C3.1, R48.2
unnamed: J29.8, R51.1
unnamed: Q7.3, R51.2
unnamed: LS4.-, Q8.3
unnamed: Q8.1, R52.2
RX1: J1.19, J8.6
RX2: J9.19, J16.6
RX3: J17.19, J24.6
RX4: J25.19, J32.6
SCL: J1.14, J4.3, J6.4, R7.1, U2.9
SCL1: J9.14, J12.3, J14.4, R21.1, U1.9
SCL2: J17.14, J20.3, J22.4, R34.1, U4.9
SCL3: J25.14, J28.3, J30.4, R47.1, U7.9
SDA: J1.12, J4.4, J6.3, R8.1, U2.7
SDA1: J9.12, J12.4, J14.3, R22.1, U1.7
SDA2: J17.12, J20.4, J22.3, R35.1, U4.7
SDA3: J25.12, J28.4, J30.3, R48.1, U7.7
SPI_CIPO: J1.61, J2.DO, J5.28
SPI_CIPO1: J9.61, J10.DO, J13.28
SPI_CIPO2: J17.61, J18.DO, J21.28
SPI_CIPO3: J25.61, J26.DO, J29.28
SPI_COPI: J1.59, J2.DI, J5.39
SPI_COPI1: J9.59, J10.DI, J13.39
SPI_COPI2: J17.59, J18.DI, J21.39
SPI_COPI3: J25.59, J26.DI, J29.39
SPI_SCK: J1.57, J2.SCLK, J5.33
SPI_SCK1: J9.57, J10.SCLK, J13.33
SPI_SCK2: J17.57, J18.SCLK, J21.33
SPI_SCK3: J25.57, J26.SCLK, J29.33
SWDCK: J1.21, J7.4, TP1.P$1
SWDCK1: J9.21, J15.4, TP2.P$1
SWDCK2: J17.21, J23.4, TP3.P$1
SWDCK3: J25.21, J31.4, TP4.P$1
SWDIO: J1.23, J7.2
SWDIO1: J9.23, J15.2
SWDIO2: J17.23, J23.2
SWDIO3: J25.23, J31.2
TX1: J1.17, J8.7
TX2: J9.17, J16.7
TX3: J17.17, J24.7
TX4: J25.17, J32.7
USB_D+: J1.3, J3.A6, J3.B6
USB_D+1: J9.3, J11.A6, J11.B6
USB_D+2: J17.3, J19.A6, J19.B6
USB_D+3: J25.3, J27.A6, J27.B6
USB_D-: J1.5, J3.A7, J3.B7
USB_D-1: J9.5, J11.A7, J11.B7
USB_D-2: J17.5, J19.A7, J19.B7
USB_D-3: J25.5, J27.A7, J27.B7
VIN: BYP.2, C1.1, C2.+, C13.1, F2.2, J1.9, R5.2, U5.8
VIN1: BYP1.2, C8.1, C10.1, C11.+, F1.2, J9.9, R18.2, U3.8
VIN2: BYP2.2, C19.1, C21.1, C22.+, F3.2, J17.9, R31.2, U6.8
VIN3: BYP3.2, C28.1, C30.1, C31.+, F4.2, J25.9, R44.2, U8.8
V_USB: BYP.1, F2.1, J3.VBUS1, J3.VBUS2, J8.1
V_USB1: BYP1.1, F1.1, J11.VBUS1, J11.VBUS2, J16.1
V_USB2: BYP2.1, F3.1, J19.VBUS1, J19.VBUS2, J24.1
V_USB3: BYP3.1, F4.1, J27.VBUS1, J27.VBUS2, J32.1

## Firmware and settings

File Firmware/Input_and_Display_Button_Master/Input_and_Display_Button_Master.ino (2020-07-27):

/*
  An I2C based Button
  By: Nathan Seidle and Fischer Moseley and Priyanka Makin
  SparkFun Electronics
  Date: July 31st, 2019
  License: This code is public domain but you buy me a beer if you use this and
  we meet someday (Beerware license).

  Qwiic Button is an I2C based button that records any button presses to a queue.

  Qwiic Button maintains a queue of events. To remove events from the queue write
  the appropriate register (timeSinceLastButtonClicked or timeSinceLastButtonPressed)
  to zero. The register will then be filled with the next available event time.

  There is also an accompanying Arduino Library located here:
  https://github.com/sparkfun/SparkFun_Qwiic_Button_Arduino_Library

  Feel like supporting our work? Buy a board from SparkFun!
  https://www.sparkfun.com/products/14641

  To install support for ATtiny84 in Arduino IDE: https://github.com/SpenceKonde/ATTinyCore/blob/master/Installation.md
  This core is installed from the Board Manager menu
  This core has built in support for I2C S/M and serial
  If you have Dave Mellis' ATtiny installed you may need to remove it from \Users\xx\AppData\Local\Arduino15\Packages

  To support 400kHz I2C communication reliably ATtiny84 needs to run at 8MHz. This requires user to
  click on 'Burn Bootloader' before code is loaded.

  Library Inclusion:
  Wire.h        Used for interfacing with the I2C hardware for responding to I2C events.
  EEPROM.h      Used for interfacing with the onboard EEPROM for storing and retrieving settings.
  nvm.h         Used for defining the storage locations in non-volatile memory (EEPROM) to store and retrieve settings from.
  queue.h       Used for defining a FIFO-queue that contains the timestamps associated with pressing and clicking the button.
  registers.h   Used for defining a memoryMap object that serves as the register map for the device.
  led.h         Used for configuring the behavior of the onboard LED (in the case of the Qwiic Button)
                  or the offboard LED (in the case of the Qwiic Switch)

  PinChangeInterrupt.h    Nico Hoo's library for triggering an interrupt on a pin state change (either low->high or high->low)
  avr/sleep.h             Needed for sleep_mode which saves power on the ATTiny
  avr/power.hardware      Needed for powering down peripherals such as the ADC/TWI and Timers on the ATTiny
*/

#include <Wire.h>
#include <EEPROM.h>
#include "nvm.h"
#include "registers.h"

#include "PinChangeInterrupt.h" //Nico Hood's library: https://github.com/NicoHood/PinChangeInterrupt/
//Used for pin change interrupts on ATtinys (encoder button causes interrupt)
//Note: To make this code work with Nico's library you have to comment out https://github.com/NicoHood/PinChangeInterrupt/blob/master/src/PinChangeInterruptSettings.h#L228

#include <avr/sleep.h> //Needed for sleep_mode
#include <avr/power.h> //Needed for powering down perihperals such as the ADC/TWI and Timers

#define DEVICE_ID 0xAE
#define FIRMWARE_MAJOR 0x01 //Firmware Version. Helpful for tech support.
#define FIRMWARE_MINOR 0x00

#define DEFAULT_I2C_ADDRESS 0x71

#define SOFTWARE_ADDRESS true
#define HARDWARE_ADDRESS false

uint8_t oldAddress;

#define NUM_BUTTONS             7
#define EVENT_AVAILABLE         7 //Position of the EVENT_AVAILABLE bit
#define BUTTON_PIN_A            10
#define BUTTON_PIN_B            9
#define BUTTON_PIN_UP           2
#define BUTTON_PIN_DOWN         0
#define BUTTON_PIN_LEFT         8
#define BUTTON_PIN_RIGHT        1
#define BUTTON_PIN_CENTER       3

enum buttons {
  A,
  B,
  UP,
  DOWN,
  LEFT,
  RIGHT,
  CENTER
};

//Hardware connections
#if defined(__AVR_ATmega328P__)
//For developement on an Uno
const uint8_t addressPin0 = 3;
const uint8_t addressPin1 = 4;
const uint8_t addressPin2 = 5;
const uint8_t addressPin3 = 6;
const uint8_t ledPin = 9; //PWM
const uint8_t statusLedPin = 8;
const uint8_t switchPin = 2;
const uint8_t interruptPin = 7; //pin is active-low, high-impedance when not triggered, goes low-impedance to ground when triggered

#elif defined(__AVR_ATtiny84__)
const uint8_t buttonPin[NUM_BUTTONS] = {BUTTON_PIN_A, BUTTON_PIN_B, BUTTON_PIN_UP, BUTTON_PIN_DOWN, BUTTON_PIN_LEFT, BUTTON_PIN_RIGHT, BUTTON_PIN_CENTER};
const uint8_t interruptPin = 7; //pin is active-low, high-impedance when not triggered, goes low-impedance to ground when triggered
#endif

//Global variables
//-=-=-=-=-=-=-=-=-=-=-=-=-=-=-=-=-=-=-=-=-=-=-=-=-=-=-=-=-=-=-=-=-=-=-=-=-=-=-=-=-=-=-=-=-=-
//These are the defaults for all settings

//Variables used in the I2C interrupt.ino file so we use volatile
volatile memoryMap registerMap {
  DEVICE_ID,                //id
  FIRMWARE_MINOR,           //firmwareMinor
  FIRMWARE_MAJOR,           //firmwareMajor
  0x00,                     //pressedStatus {EventAvailable, center, right, left, down, up, b, a}
  0x00,                     //clickedStatus {EventAvailable, center, right, left, down, up, b, a}
  {1, 1},                   //interruptConfig {pressedEnable, clickedEnable}
  0x000A,                   //buttonDebounceTime
  DEFAULT_I2C_ADDRESS,      //i2cAddress
};

//This defines which of the registers are read-only (0) vs read-write (1)
memoryMap protectionMap = {
  0x00,       //id
  0x00,       //firmwareMinor
  0x00,       //firmwareMajor
  0x00,       //clickedStatus {A(MSB), B, Up, Down, Left, Right, Center, eventAvailable (LSB)}
  0x00,       //pressedStatus {A(MSB), B, Up, Down, Left, Right, Center, eventAvailable (LSB)}
  {1, 1},     //interruptConfig {pressedEnable, clickedEnable}
  0xFFFF,     //buttonDebounceTime
  0xFF,       //i2cAddress
};

//Cast 32bit address of the object registerMap with uint8_t so we can increment the pointer
uint8_t *registerPointer = (uint8_t *)&registerMap;
uint8_t *protectionPointer = (uint8_t *)&protectionMap;

volatile uint8_t registerNumber; //Gets set when user writes an address. We then serve the spot the user requested.

volatile boolean updateFlag = true; //Goes true when we receive new bytes from user. Causes LEDs and things to update in main loop.

volatile unsigned long lastClickTime = 0; //Used for debouncing

//-=-=-=-=-=-=-=-=-=-=-=-=-=-=-=-=-=-=-=-=-=-=-=-=-=-=-=-=-=-=-=-=-=-=-=-=-=-=-=-=-=-=-=-=-=-

void setup(void)
{
  //Enable Pullups on all buttons
  for (int buttonNum = 0; buttonNum < NUM_BUTTONS; buttonNum++)
  {
    pinMode(buttonPin[buttonNum], INPUT_PULLUP); //GPIO with internal pullup, goes low when button is pushed
  }

#if defined(__AVR_ATmega328P__)
  pinMode(interruptPin, INPUT_PULLUP);     //High-impedance input until we have an int and then we output low. Pulled high with 10k with cuttable jumper.
#else
  pinMode(interruptPin, INPUT_PULLUP);     //High-impedance input until we have an int and then we output low. Pulled high with 10k with cuttable jumper.
#endif

  //Disable ADC
  ADCSRA = 0;

  //Disable Brown-Out Detect
  MCUCR = bit(BODS) | bit(BODSE);
  MCUCR = bit(BODS);

  //Power down various bits of hardware to lower power usage
  //set_sleep_mode(SLEEP_MODE_PWR_DOWN); //May turn off millis
  set_sleep_mode(SLEEP_MODE_IDLE);
  sleep_enable();

#if defined(__AVR_ATmega328P__)

  for (int x = 0; x < 100; x++) {
    EEPROM.put(x, 0xFF);
  }

  Serial.begin(115200);
  Serial.println("Qwiic Button");
  Serial.print("Address: 0x");
  Serial.println(registerMap.i2cAddress, HEX);
  Serial.print("Device ID: 0x");
  Serial.println(registerMap.id, HEX);

#endif

  //readSystemSettings(&registerMap); //Load all system settings from EEPROM

#if defined(__AVR_ATmega328P__)

#endif

  setupInterrupts();               //Enable pin change interrupts for I2C, switch, etc
  startI2C(&registerMap);          //Determine the I2C address we should be using and begin listening on I2C bus
  oldAddress = registerMap.i2cAddress;

}

void loop(void)
{
  //Check to see if the I2C Address has been updated by software, set the appropriate address type flag
  if (oldAddress != registerMap.i2cAddress)
  {
    oldAddress = registerMap.i2cAddress;
    EEPROM.put(LOCATION_ADDRESS_TYPE, SOFTWARE_ADDRESS);
  }

  //update interruptPin output
  if ((((registerMap.pressedStatus & (1 << EVENT_AVAILABLE)) >> EVENT_AVAILABLE) && registerMap.interruptConfigure.pressedEnable) ||
      (((registerMap.clickedStatus & (1 << EVENT_AVAILABLE)) >> EVENT_AVAILABLE) && registerMap.interruptConfigure.clickedEnable))
  { //if the interrupt is triggered
    pinMode(interruptPin, OUTPUT); //make the interrupt pin a low-impedance connection to ground
    digitalWrite(interruptPin, LOW);
  }
  else
  { //go to high-impedance mode on the interrupt pin if the interrupt is not triggered
#if defined(__AVR_ATmega328P__)
    pinMode(interruptPin, INPUT_PULLUP);
#else
    pinMode(interruptPin, INPUT_PULLUP);
#endif
  }

  if (updateFlag == true)
  {
    //Record anything new to EEPROM (like new LED values)
    //It can take ~3.4ms to write a byte to EEPROM so we do that here instead of in an interrupt
    recordSystemSettings(&registerMap);

    //Calculate LED values based on pulse settings if anything has changed

    updateFlag = false; //clear flag
  }

  sleep_mode();             //Stop everything and go to sleep. Wake up if I2C event occurs.
}

//Update slave I2C address to what's configured with registerMap.i2cAddress and/or the address jumpers.
void startI2C(memoryMap *map)
{
  uint8_t address;
  //if the value is legal, then set it
  if (map->i2cAddress > 0x07 && map->i2cAddress < 0x78)
    address = map->i2cAddress;

  //if the value is illegal, default to the default I2C address for our platform
  else
    address = DEFAULT_I2C_ADDRESS;

  //save new address to the register map
  map->i2cAddress = address;

  //reconfigure Wire instance
  Wire.end();          //stop I2C on old address
  Wire.begin(address); //rejoin the I2C bus on new address

  //The connections to the interrupts are severed when a Wire.begin occurs, so here we reattach them
  Wire.onReceive(receiveEvent);
  Wire.onRequest(requestEvent);
}

//Reads the current system settings from EEPROM
//If anything looks weird, reset setting to default value
void readSystemSettings(memoryMap *map)
{
  //Read what I2C address we should use
  EEPROM.get(LOCATION_I2C_ADDRESS, map->i2cAddress);
  if (map->i2cAddress == 255)
  {
    map->i2cAddress = DEFAULT_I2C_ADDRESS; //By default, we listen for DEFAULT_I2C_ADDRESS
    EEPROM.put(LOCATION_I2C_ADDRESS, map->i2cAddress);
  }

  //Error check I2C address we read from EEPROM
  if (map->i2cAddress < 0x08 || map->i2cAddress > 0x77)
  {
    //User has set the address out of range
    //Go back to defaults
    map->i2cAddress = DEFAULT_I2C_ADDRESS;
    EEPROM.put(LOCATION_I2C_ADDRESS, map->i2cAddress);
  }

  //Read the interrupt bits
  EEPROM.get(LOCATION_INTERRUPTS, map->interruptConfigure.byteWrapped);
  if (map->interruptConfigure.byteWrapped == 0xFF)
  {
    map->interruptConfigure.byteWrapped = 0x03; //By default, enable the click and pressed interrupts
    EEPROM.put(LOCATION_INTERRUPTS, map->interruptConfigure.byteWrapped);
  }

  EEPROM.get(LOCATION_BUTTON_DEBOUNCE_TIME, map->buttonDebounceTime);
  if (map->buttonDebounceTime == 0xFFFF)
  {
    map->buttonDebounceTime = 10; //Default to 10ms
    EEPROM.put(LOCATION_BUTTON_DEBOUNCE_TIME, map->buttonDebounceTime);
  }

}

//If the current setting is different from that in EEPROM, update EEPROM
void recordSystemSettings(memoryMap *map)
{
  //I2C address is byte
  byte i2cAddr;

  //Error check the current I2C address
  if (map->i2cAddress >= 0x08 && map->i2cAddress <= 0x77)
  {
    //Address is valid

    //Read the value currently in EEPROM. If it's different from the memory map then record the memory map value to EEPROM.
    EEPROM.get(LOCATION_I2C_ADDRESS, i2cAddr);
    if (i2cAddr != map->i2cAddress)
    {
      EEPROM.put(LOCATION_I2C_ADDRESS, (byte)map->i2cAddress);
      startI2C(map); //Determine the I2C address we should be using and begin listening on I2C bus
    }
  }
  else
  {
    EEPROM.get(LOCATION_I2C_ADDRESS, i2cAddr);
    map->i2cAddress == i2cAddr; //Return to original address
  }


  EEPROM.put(LOCATION_INTERRUPTS, map->interruptConfigure.byteWrapped);
  EEPROM.put(LOCATION_BUTTON_DEBOUNCE_TIME, map->buttonDebounceTime);
}

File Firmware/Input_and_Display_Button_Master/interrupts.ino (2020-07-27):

/******************************************************************************
  interrupts.ino
  Fischer Moseley @ SparkFun Electronics
  Original Creation Date: July 31, 2019

  This file contains the interrupt routines that are triggered upon an I2C write from
  master (receiveEvent), an I2C read (requestEvent), or a button state change
  (buttonInterrupt). These ISRs modify the registerMap state variable, and sometimes
  set a flag (updateFlag) that updates things in the main loop.

  This code is beerware; if you see me (or any other SparkFun employee) at the
  local, and you've found our code helpful, please buy us a round!

  Distributed as-is; no warranty is given.
******************************************************************************/

//Turn on interrupts for the various pins
void setupInterrupts() {
  //Attach interrupt to switch
  for (int buttonNum = 0; buttonNum < NUM_BUTTONS; buttonNum++)
  {
    attachPCINT(digitalPinToPCINT(buttonPin[buttonNum]), buttonInterrupt, CHANGE);
  }
}

//When Qwiic Button receives data bytes from Master, this function is called as an interrupt
void receiveEvent(int numberOfBytesReceived) {
  registerNumber = Wire.read(); //Get the memory map offset from the user

  //Begin recording the following incoming bytes to the temp memory map
  //starting at the registerNumber (the first byte received)
  for (uint8_t x = 0 ; x < numberOfBytesReceived - 1 ; x++) {
    uint8_t temp = Wire.read(); //We might record it, we might throw it away

    if ( (x + registerNumber) < sizeof(memoryMap)) {
      //Clense the incoming byte against the read only protected bits
      //Store the result into the register map
      *(registerPointer + registerNumber + x) &= ~*(protectionPointer + registerNumber + x); //Clear this register if needed
      *(registerPointer + registerNumber + x) |= temp & *(protectionPointer + registerNumber + x); //Or in the user's request (clensed against protection bits)
    }
  }

  updateFlag = true; //Update things like LED brightnesses in the main loop
}

//Respond to GET commands
//When Qwiic Button gets a request for data from the user, this function is called as an interrupt
//The interrupt will respond with bytes starting from the last byte the user sent to us
//While we are sending bytes we may have to do some calculations
void requestEvent() {

  //This will write the entire contents of the register map struct starting from
  //the register the user requested, and when it reaches the end the master
  //will read 0xFFs.
  Wire.write((registerPointer + registerNumber), sizeof(memoryMap) - registerNumber);

  if (registerNumber == 0x03) //Clear our EVENT_AVAILABLE flag to clear the interrupt
  {
    registerMap.pressedStatus &= ~(1 << EVENT_AVAILABLE);
    
  }
  if (registerNumber == 0x04) //Clear our Entire Register
  {
    registerMap.clickedStatus &= 0x00;
  }
}

//Called any time the pin changes state
void buttonInterrupt() {

  //Debounce
  if (millis() - lastClickTime < registerMap.buttonDebounceTime)
    return;
  lastClickTime = millis();

  registerMap.pressedStatus |= true << EVENT_AVAILABLE;

  for (int buttonNum = 0; buttonNum < NUM_BUTTONS; buttonNum++)
  {
    bool previousState = (registerMap.pressedStatus & (1 << buttonNum)); //Get previous button state to see if it has changed since the last interrupt
    bool currentState = !digitalRead(buttonPin[buttonNum]);
    registerMap.pressedStatus &= ~(1 << buttonNum);
    registerMap.pressedStatus |= (currentState << buttonNum);
    if ((currentState == LOW) && (currentState != previousState))
    {
      registerMap.clickedStatus |= (1 << buttonNum);
      registerMap.clickedStatus |= true << EVENT_AVAILABLE;
    }
  }
}

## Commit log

2020-07-28 Pre-review changes
    Added SWD connector
    Updated SPI names
    [SparkFun_MicroMod_Input_and_Display_Carrier.brd, SparkFun_MicroMod_Input_and_Display_Carrier.sch]
2020-07-29 Post review changes
    - Added notes for jumpers
    - Changed SPI_CS to SD_CS label
    - Connected display reset to IO
    - Added NO jumper between MicroMod and regulator enable
    - Added Buzzer to PWM1
    - Broke out A0/1, RX1/TX1, CAN-RX/TX, 3.3V, and GND
    - Added name on back of the board
    - Fixed or corrected DRC errors
    - Fixed non-mitered corners
    - Moved reset and boot buttons
    - Added indicator for "UP" on 5-way switch
    [SparkFun_MicroMod_Input_and_Display_Carrier.brd, SparkFun_MicroMod_Input_and_Display_Carrier.sch]
2020-07-30 QC Fixes
    [SparkFun_MicroMod_Input_and_Display_Carrier.brd, SparkFun_MicroMod_Input_and_Display_Carrier.sch]
2020-08-17 v01 update
    -Added 10ohm resistor to backlight
    -Added 10k pullup to tft reset
    -Connected Attiny reset to MM reset
    [SparkFun_MicroMod_Input_and_Display_Carrier.brd, SparkFun_MicroMod_Input_and_Display_Carrier.sch]
2020-08-18 v10
    Moved display cable back slightly
    Moved A and B buttons closer together
    Moved measures jumper away from button A
    Added silk to display outline
    [SparkFun_MicroMod_Input_and_Display_Carrier.brd, SparkFun_MicroMod_Input_and_Display_Carrier.sch]
2020-08-19 v10 post review changes
    -Added 5V/V_USB pin
    -Added BJT to buzzer
    -Replaced pull up/down resistors from 10lk to 100k
    -Replaced 1/10W 10ohm resistor with 1/4W 10ohm
    -Removed display outline on tPlace layer
    [SparkFun_MicroMod_Input_and_Display_Carrier.brd, SparkFun_MicroMod_Input_and_Display_Carrier.sch]
2020-08-19 v10 cleanup
    -Updated active low labels
    -Fixed Attiny I2C address
    -Updated measures layer
    [SparkFun_MicroMod_Input_and_Display_Carrier.brd, SparkFun_MicroMod_Input_and_Display_Carrier.sch]
2020-08-20 QC fixes
    - Added note for MEAS jumper
    - Adjusted button B label
    [SparkFun_MicroMod_Input_and_Display_Carrier.brd, SparkFun_MicroMod_Input_and_Display_Carrier.sch]
2020-08-20 Added production files
    [SparkFun_MicroMod_Input_and_Display_Carrier-Panel.GBL, SparkFun_MicroMod_Input_and_Display_Carrier-Panel.GBO, SparkFun_MicroMod_Input_and_Display_Carrier-Panel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]
2020-08-25 Updated Bottom Stencil for MM connector
    [SparkFun_MicroMod_Input_and_Display_Carrier-Panel.GBP]
2020-09-10 v11
    Updated MM conenctor SPI pins
    [SparkFun_MicroMod_Input_and_Display_Carrier.brd, SparkFun_MicroMod_Input_and_Display_Carrier.sch]
2020-09-16 Added V11 panel
    [SparkFun_MicroMod_Input_and_Display_Carrier-Panel.brd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]

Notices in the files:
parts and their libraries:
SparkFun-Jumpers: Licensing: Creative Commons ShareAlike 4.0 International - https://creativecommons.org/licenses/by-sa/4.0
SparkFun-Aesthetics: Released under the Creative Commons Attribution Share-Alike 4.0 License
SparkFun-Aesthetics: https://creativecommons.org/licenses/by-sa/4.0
